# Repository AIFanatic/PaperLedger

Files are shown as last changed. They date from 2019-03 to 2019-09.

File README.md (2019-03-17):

# PaperLedger

Custom made crypto price ticker with alarms

## Getting Started

* [Initial setup](./docs/setup.md "Initial setup")
* [Adding tickers](./docs/add_tickers.md "Adding tickers")
* [Adding alarms](./docs/add_alarms.md "Adding alarms")
* [Updating firmware](./docs/update_firmware.md "Updating firmware")

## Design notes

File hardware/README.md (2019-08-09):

# PaperLedger - Hardware

Note that the currently available materials on the market may be different from the ones listed.

# Bill of materials

## Electronic parts

| Description | SKU | Quantity  | Price  |  Link  |
| --- |:---:| -----:| -----:| -----:|
| TTGO T5 V2.2 ESP32 2.9" EPaper | 32850386996 | 1 | 22.68 USD | [Aliexpress](https://www.aliexpress.com/item/TTGO-T5-V2-2-ESP32-2-9-EPaper-Plus-Module-e-Ink-Speakers/32850386996.html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,searchweb201602_6_10065_10068_10130_10547_319_317_10548_10696_453_10084_454_10083_10618_10307_537_536_10131_10132_10902_10133_10059_10884_10887_321_322_10103,searchweb201603_51,ppcSwitch_0&algo_expid=27d31c4f-6f7f-46df-963b-0b2262c63b45-0&algo_pvid=27d31c4f-6f7f-46df-963b-0b2262c63b45&transAbTest=ae803_4) |
| USB Micro-B Connector Breakout Board | 2586 | 1 | 1.49 USD | [Pololu](https://www.pololu.com/product/2586) |

## 3D Printed parts

| Description | Quantity |
| --- |:---:|
| Front.stl | 1 |
| Back.stl | 1 |
| Buttons.stl | 1 |

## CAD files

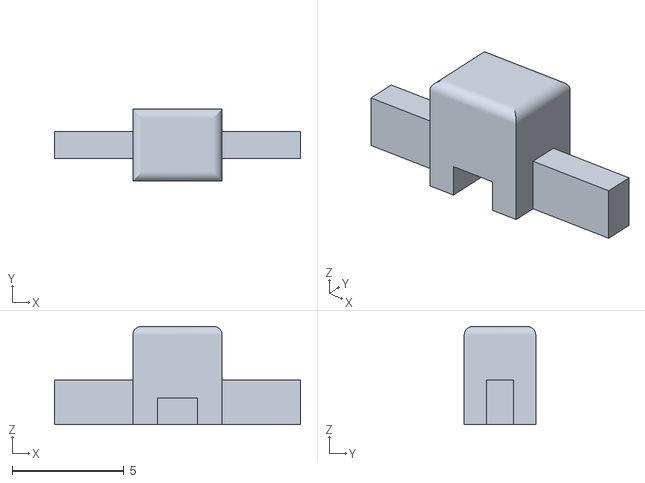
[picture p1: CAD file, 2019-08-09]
hardware/Button_on_off.stl
11.0 x 3.20 x 4.40

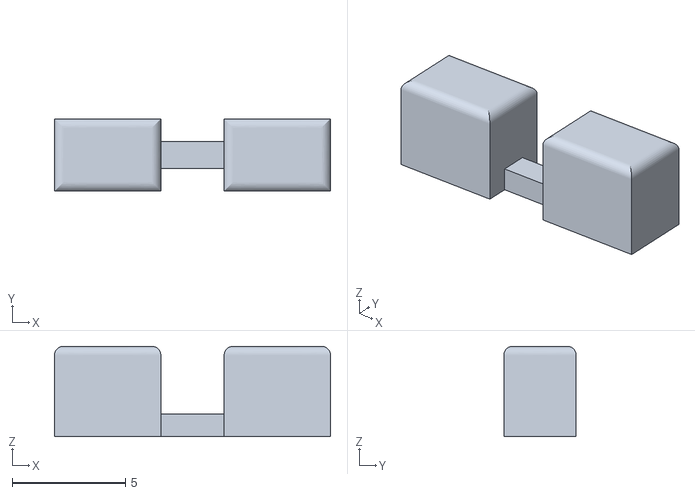
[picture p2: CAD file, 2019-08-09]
hardware/Buttons.stl
12.2 x 3.20 x 4.00

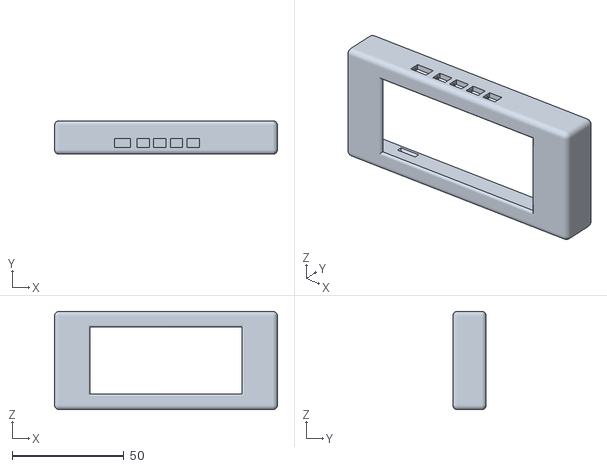
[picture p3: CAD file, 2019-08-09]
hardware/Front.stl
100.0 x 15.0 x 44.0

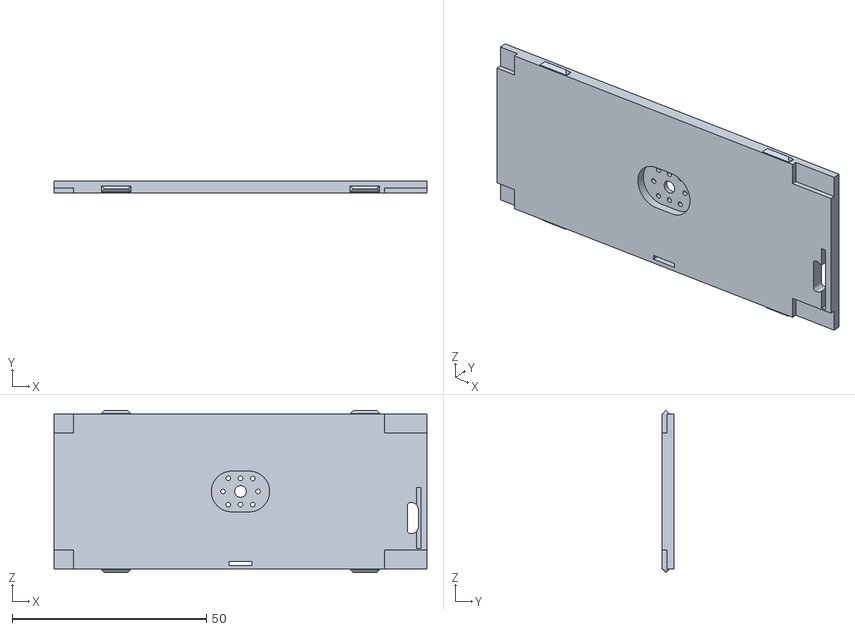
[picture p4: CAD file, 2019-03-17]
hardware/Back.stl
96.0 x 3.01 x 41.8

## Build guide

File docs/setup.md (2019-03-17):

# PaperLedger Guides
## Initial setup

1. Power on the device by connecting the usb cable at the back of the device

2. Wait for the device to boot and show *No Internet*

3. Using another Wifi capable device search for networks and connect to *PaperLedger*

4. Using any browser navigate to *http://paperledger.local*

5. Click *Setup network* and wait for the device to query the available Wifi networks

6. Click on the tick button next to the desired network, enter the Wifi password and click connect.

7. After a few seconds the device should either reboot or go to the main menu, meaning that it is connected

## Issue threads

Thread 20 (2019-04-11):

Solve networking issues

AIFanatic, 2019-04-11:
In GitLab by @nm on Jan 3, 2019, 00:40

Sometimes if in AP mode and the user browses the ip the device crashes

AP first client connect:
```
Guru Meditation Error: Core  1 panic'ed (LoadProhibited). Exception was unhandled.
Core 1 register dump:
PC      : 0x400dbbae  PS      : 0x00060b30  A0      : 0x800dbbd5  A1      : 0x3ffd2930
A2      : 0x3ffd29e8  A3      : 0x3ffb85f4  A4      : 0x3ffcecd8  A5      : 0x3f401867
A6      : 0x00ff0000  A7      : 0xff000000  A8      : 0x00000001  A9      : 0x3ffd2910
A10     : 0x3ffd2938  A11     : 0x3ffcd6f0  A12     : 0x3ffcecd8  A13     : 0x3f401867
A14     : 0x00000072  A15     : 0xff000000  SAR     : 0x00000020  EXCCAUSE: 0x0000001c
EXCVADDR: 0x00000009  LBEG    : 0x4000c46c  LEND    : 0x4000c477  LCOUNT  : 0x00000000

Backtrace: 0x400dbbae:0x3ffd2930 0x400dbbd2:0x3ffd2960 0x400dd539:0x3ffd2980 0x400dd5d1:0x3ffd2a20 0x400dd6f3:0x3ffd2a60 0x400e1c65:0x3ffd2a90 0x400df60d:0x3ffd2ac0 0x400df6ed:0x3ffd2b00 0x400df945:0x3ffd2b50 0x40147ba5:0x3ffd2b70 0x40147e72:0x3ffd2bb0

0x4000c349
0x4000c349: ?? ??:0
0x4000c36b
0x4000c36b: ?? ??:0
0x40116a92:0x3ffbeb80
0x40116a92: handle_dhcp at /Users/ficeto/Desktop/ESP32/ESP32/esp-idf-public/components/lwip/apps/dhcpserver.c:1035
0x4011ea31:0x3ffbeba0
0x4011ea31: udp_input at /Users/ficeto/Desktop/ESP32/ESP32/esp-idf-public/components/lwip/core/udp.c:417
0x401215dd:0x3ffbebe0
0x401215dd: ip4_input at /Users/ficeto/Desktop/ESP32/ESP32/esp-idf-public/components/lwip/core/ipv4/ip4.c:705
0x40127586:0x3ffbec00
0x40127586: ethernet_input at /Users/ficeto/Desktop/ESP32/ESP32/esp-idf-public/components/lwip/netif/ethernet.c:176
0x40115e55:0x3ffbec20
0x40115e55: tcpip_thread at /Users/ficeto/Desktop/ESP32/ESP32/esp-idf-public/components/lwip/api/tcpip.c:474
```

Wifi first connect (coming from AP mode):
```
Guru Meditation Error: Core  1 panic'ed (LoadProhibited). Exception was unhandled.
Core 1 register dump:
PC      : 0x400dbbae  PS      : 0x00060b30  A0      : 0x800dbbd5  A1      : 0x3ffd2930
A2      : 0x3ffd29e8  A3      : 0x3ffb85f4  A4      : 0x3ffcecd8  A5      : 0x3f401867
A6      : 0x00ff0000  A7      : 0xff000000  A8      : 0x00000001  A9      : 0x3ffd2910
A10     : 0x3ffd2938  A11     : 0x3ffcd6f0  A12     : 0x3ffcecd8  A13     : 0x3f401867
A14     : 0x00000072  A15     : 0xff000000  SAR     : 0x00000020  EXCCAUSE: 0x0000001c
EXCVADDR: 0x00000009  LBEG    : 0x4000c46c  LEND    : 0x4000c477  LCOUNT  : 0x00000000

Backtrace: 0x400dbbae:0x3ffd2930 0x400dbbd2:0x3ffd2960 0x400dd539:0x3ffd2980 0x400dd5d1:0x3ffd2a20 0x400dd6f3:0x3ffd2a60 0x400e1c65:0x3ffd2a90 0x400df60d:0x3ffd2ac0 0x400df6ed:0x3ffd2b00 0x400df945:0x3ffd2b50 0x40147ba5:0x3ffd2b70 0x40147e72:0x3ffd2bb0

0x400dbbae
0x400dbbae: fs::FS::open(char const*, char const*) at ??:?
0x4000c46c
0x4000c46c: ?? ??:0
0x4000c477
0x4000c477: ?? ??:0
0x400dbbae:0x3ffd2930
0x400dbbae: fs::FS::open(char const*, char const*) at ??:?
0x400dbbd2:0x3ffd2960
0x400dbbd2: fs::FS::open(String const&, char const*) at ??:?
0x400dd539:0x3ffd2980
0x400dd539: AsyncStaticWebHandler::_fileExists(AsyncWebServerRequest*, String const&) at ??:?
0x400dd5d1:0x3ffd2a20
0x400dd5d1: AsyncStaticWebHandler::_getFile(AsyncWebServerRequest*) at ??:?
0x400dd6f3:0x3ffd2a60
0x400dd6f3: AsyncStaticWebHandler::canHandle(AsyncWebServerRequest*) at ??:?
0x400e1c65:0x3ffd2a90
0x400e1c65: AsyncWebServer::_attachHandler(AsyncWebServerRequest*) at ??:?
0x400df60d:0x3ffd2ac0
0x400df60d: AsyncWebServerRequest::_parseLine() at ??:?
0x400df6ed:0x3ffd2b00
0x400df6ed: AsyncWebServerRequest::_onData(void*, unsigned int) at ??:?
0x400df945:0x3ffd2b50
0x400df945: std::_Function_handler<void (void*, AsyncClient*, void*, unsigned int), AsyncWebServerRequest::AsyncWebServerRequest(AsyncWebServer*, AsyncClient*)::{lambda(void*, AsyncClient*, void*, unsigned int)#7}>::_M_invoke(std::_Any_data const&, void*&&, AsyncClient*&&, std::_Any_data const&, unsigned int&&) at WebRequest.cpp:?
0x40147ba5:0x3ffd2b70
0x40147ba5: AsyncClient::_recv(tcp_pcb*, pbuf*, signed char) at ??:?
0x40147e72:0x3ffd2bb0
0x40147e72: _async_service_task(void*) at AsyncTCP.cpp:?
```

AIFanatic, 2019-04-11:
In GitLab by @nm on Jan 3, 2019, 00:40

Solve Wifi/AP reconnect change credentials crashing

AIFanatic, 2019-04-11:
In GitLab by @nm on Jan 3, 2019, 19:53

changed title from **Solve {-wifi-} issues** to **Solve {+AP+} issues**

AIFanatic, 2019-04-11:
In GitLab by @nm on Jan 3, 2019, 19:53

changed the description

AIFanatic, 2019-04-11:
In GitLab by @nm on Jan 4, 2019, 21:45

changed title from **Solve {-AP-} issues** to **Solve {+networking+} issues**

AIFanatic, 2019-04-11:
In GitLab by @nm on Jan 4, 2019, 21:45

changed the description

AIFanatic, 2019-04-11:
In GitLab by @nm on Jan 25, 2019, 23:40

changed the description

AIFanatic, 2019-04-11:
In GitLab by @nm on Jan 26, 2019, 15:18

Solved AP issues: https://github.com/espressif/arduino-esp32/issues/2283

AIFanatic, 2019-04-11:
In GitLab by @nm on Jan 26, 2019, 17:44

closed

AIFanatic, 2019-07-30:
The device still has issues with connectivity.
It seems that the latest version of Espressif 32 (1.9.0) has some networking issues.
The device behaves unpredictably specially in AP mode (slow, ack lost, cant ping gateway, etc)

By applying the changes below the device seems to be stable so far.
https://github.com/espressif/arduino-esp32/issues/3037#issuecomment-516095167

Closed 2019-04-11.

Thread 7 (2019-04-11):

[Feature Request] Price graph of a coin

BitcoinMitchell, 2019-04-11:
It might be nice to have a graph that shows a coin's price.

How I envision it is being able to select the coin you want to watch (since switching between coins might be a bit too confusing) and just draw a graph by pulling the data from some API.

AIFanatic, 2019-04-11:
It was in my plans to add something like this and after some digging I've found this: https://github.com/G6EJD/ESP32-e-Paper-Weather-Display/blob/master/ESP32_OWM_Current_Forecast_42_epaper_v11.ino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

It seems that a simple graph would be easy enough to implement. Also by combining a candle chart with a volume bar below, there is no need to display the price nor the volume anymore thus simplifying the layout.
Only worry is the size of the screen/chart may become to small to be readable at a comfortable distance.

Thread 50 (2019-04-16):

[Hardware] Add a battery

AIFanatic, 2019-04-16:
A battery would complement the device very well and after some research here is some info.

- In order to not change the case design a maximum battery capacity is around 500mah, this should be enough with deep sleep implemented.
- According to the schematics found at https://github.com/lewisxhe/TTGO-Electronic-Badge/blob/master/schematic/T5_V2.2.pdf the VBAT pin is not connected to the ESP32 so a "manual" connection has to be made, possibly to pin IO34.
- The GPIO on the ESP32 works at a 3.3v level and the battery is 3.7v (4.0v while charging) so a voltage divider has to be added to the board in order to bring the voltages down.
- The board already has a charging circuit but the charging LED (or any charging signal) is not available in the GPIO header, so either "charging mode" is detected by voltage increase on VBAT or "LED_G LED0603 BLUE" has to be remapped to the available GPIO.

AIFanatic, 2019-05-13:
Updates:
- In addition to the VBAT pin the charging pin (VBUS/CHRG) is hardwired to the onboard USB which will be hard to get around without some hackish solutions. Ideally a vertical USB connector would replace the existing one thus removing the need for an extra USB.
- The cases are likely to be reprinted since the battery barely fits the existing model. A 2mm increase in depth should be enough to accommodate the battery nicely.
- The device consumes ~85mA while powered, peaking to ~150mA when pulling data.
- In deep sleep mode the device consumes 7mA which is higher than the researched values of around 10μA (https://lastminuteengineers.com/esp32-sleep-modes-power-consumption/). This is likely to be related with the onboard LED's (charding and power) that are always powered on. Ideally these would be removed in order to save power.
- Software wise, deep sleep can be implemented with ease and a prototype has been sketched out. The network connection and deep sleep functionality have to ported out of "Manager" into the modules that require it (eg: TickerView). The "Manager" module has to store the current view in RTC in order to be aware of what view the module is at since the CPU and RAM are powered off in deep sleep.

Hackish solution:
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

AIFanatic, 2019-07-28:
Updates:
- A new board has been manufactured which includes the following changes:
   - Remove SM_20PIN header.
   - Replace SM_20PIN pads with PCB through-hole.
   - Remove MICRO_USB_SMT.
   - Replace MICRO_USB_SMT pads with PCB though-hole.
   - Remove LED_G LED0603 BLUE (charging LED)
   - Remove LED_G2 LED_G LED0603 GREEN (power LED)
   - Connect VBAT with pin 13 on SM_20PIN (IO34).
   - Connect CHRG on TP4054 with pin 14 on SM_20PIN (IO33)
   - Connect RED LED to pin 12 SM_20PIN (IO26)

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

[new_board_schematic.pdf](https://github.com/AIFanatic/PaperLedger/files/3438825/new_board_schematic.pdf)

Closed 2019-08-10.

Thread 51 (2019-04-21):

[Connectivity] Device goes to Welcome screen after a while and gets stuck

AIFanatic, 2019-04-21:
Issue reported from DaveF:
https://bitcointalk.org/index.php?topic=5113453.msg50687270#msg50687270
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

Member StackGambler confirmed the issue:
>@StackGambler
> Same here. Pretty minor issue, but annoying when it happens.

BitcoinMitchell, 2019-04-25:
I haven't had this happen to me yet. Will keep an eye on it though.

AIFanatic, 2019-05-15:
It seems that by flashing the development branch firmware the issue disappeared, closing.

Closed 2019-05-15.

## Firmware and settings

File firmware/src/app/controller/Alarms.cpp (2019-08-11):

#include "Alarms.h"

#include "../Manager.h"

Alarms::Alarms(Manager *_manager) {
    manager = _manager;

    bool tickersFileExists = manager->filesystem->exists(SPIFFS, FILE_TICKERS);

    if(!tickersFileExists) {
        Serial.print("Tickers.json is not valid, creating...");

        manager->filesystem->writeFile(SPIFFS, FILE_TICKERS, "[]");
    }
};

Alarms::~Alarms() {
};

bool Alarms::add(const char *id, const char *currency, const char *price, int duration, int type, int frequency, int beeps) {

    int coinIndex = manager->tickers->getIndexOf(id, currency);

    if(coinIndex == -1) {
        return false;
    }

    String tickers = manager->tickers->get();
    DynamicJsonBuffer jsonBuffer;
    JsonArray& tickersArray = jsonBuffer.parse(tickers);

    DynamicJsonBuffer alarmBuffer;
    JsonObject& alarm = alarmBuffer.createObject();
    alarm["price"] = price;
    alarm["duration"] = duration;
    alarm["type"] = type;
    alarm["frequency"] = frequency;
    alarm["beeps"] = beeps;

    tickersArray[coinIndex]["alarms"].as<JsonArray>().add(alarm);
    
    String str;
    tickersArray.printTo(str);
    return manager->filesystem->writeFile(SPIFFS, FILE_TICKERS, str.c_str());
}

bool Alarms::remove(const char *id, const char *currency, int index) {
    int coinIndex = manager->tickers->getIndexOf(id, currency);

    if(coinIndex == -1) {
        return false;
    }

    String tickers = manager->tickers->get();
    DynamicJsonBuffer jsonBuffer;
    JsonArray& tickersArray = jsonBuffer.parse(tickers);

    tickersArray[coinIndex]["alarms"].as<JsonArray>().remove(index);

    String str;
    tickersArray.printTo(str);

    return manager->filesystem->writeFile(SPIFFS, FILE_TICKERS, str.c_str());
}

void Alarms::checkAlarms() {
    String str = manager->tickers->get();

    DynamicJsonBuffer buffer;
    JsonArray& tickersArray = buffer.parse(str);

    bool alarmTriggered = false;

    for(int i = 0; i < tickersArray.size(); i++) {
        double tickerPrice = tickersArray[i]["price"];

        JsonArray& alarms = tickersArray[i]["alarms"].as<JsonArray>();

        for(int j = 0; j < alarms.size(); j++) {
            JsonObject& alarm = alarms[j].as<JsonObject>();

            double price = alarm["price"];
            int duration = alarm["duration"];
            int type = alarm["type"];
            int frequency = alarm["frequency"];
            int beeps = alarm["beeps"];

            if(tickerPrice > 0) {
                if((type == TYPE_ABOVE && tickerPrice >= price) ||
                   (type == TYPE_BELOW && tickerPrice <= price)) {
                    manager->speaker->beep(frequency, duration / beeps, beeps);
                    manager->speaker->mute();
                    
                    alarms.remove(j);
                    alarmTriggered = true;
                }
            }
        }
    }

    if(alarmTriggered) {
        String str;
        tickersArray.printTo(str);

        manager->filesystem->writeFile(SPIFFS, FILE_TICKERS, str.c_str());
    }
}

void Alarms::requestAddAlarms(AsyncWebServerRequest *request) {
    if(!request->hasParam("id", true) || !request->hasParam("currency", true) || 
       !request->hasParam("price", true) || !request->hasParam("duration", true) ||
       !request->hasParam("type", true) || !request->hasParam("frequency", true) ||
       !request->hasParam("beeps", true)) {
        manager->webserver->requestInvalid(request);
        return;
    }

    const char *id = request->getParam("id", true)->value().c_str();
    const char *currency = request->getParam("currency", true)->value().c_str();
    const char *price = request->getParam("price", true)->value().c_str();
    int duration = request->getParam("duration", true)->value().toInt();
    int type = request->getParam("type", true)->value().toInt();
    int frequency = request->getParam("frequency", true)->value().toInt();
    int beeps = request->getParam("beeps", true)->value().toInt();


    bool ret = add(
        id, currency, 
        price, duration, 
        type, frequency, 
        beeps
    );

    request->send(200, "application/json", "{\"status\":\"ok\",\"message\":" + String(ret) + "}");
};

void Alarms::requestRemoveAlarms(AsyncWebServerRequest *request) {
    if(!request->hasParam("id", true) || !request->hasParam("currency", true) || !request->hasParam("index", true)) {
        manager->webserver->requestInvalid(request);
        return;
    }

    const char *id = request->getParam("id", true)->value().c_str();
    const char *currency = request->getParam("currency", true)->value().c_str();
    int index = request->getParam("index", true)->value().toInt();

    bool ret = remove(id, currency, index);

    request->send(200, "application/json", "{\"status\":\"ok\",\"message\":" + String(ret) + "}");
};

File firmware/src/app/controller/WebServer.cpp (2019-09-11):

#include "WebServer.h"

#include "../Manager.h"

WebServer::WebServer(Manager *_manager) {
    manager = _manager;

    DefaultHeaders::Instance().addHeader("Access-Control-Allow-Origin", "*");
};

WebServer::~WebServer() {
};

void WebServer::requestNotFound(AsyncWebServerRequest *request) {
    request->send(200, "application/json", "{\"status\":\"error\",\"message\":\"Endpoint not found\"}");
};

void WebServer::requestInvalid(AsyncWebServerRequest *request) {
    request->send(200, "application/json", "{\"status\":\"error\",\"message\":\"Invalid request\"}");
};

void WebServer::requestWifiStatus(AsyncWebServerRequest *request) {
    DynamicJsonBuffer jsonBuffer;
    JsonObject& response = jsonBuffer.createObject();
    JsonObject& message = response.createNestedObject("message");

    response["status"] = "ok";

    message["ssid"] = WiFi.SSID();
    message["rssi"] = WiFi.RSSI();
    message["internet"] = hasInternetAccess;
    
    String jsonStr;
    response.printTo(jsonStr);
    request->send(200, "application/json", jsonStr);
};

void WebServer::requestWifiList(AsyncWebServerRequest *request) {
    DynamicJsonBuffer jsonBuffer;
    JsonObject& response = jsonBuffer.createObject();

    response["status"] = "ok";

    JsonArray& message = response.createNestedArray("message");

    int n = WiFi.scanNetworks();

    if (n != 0) {
        for (int i = 0; i < n; ++i) {
            JsonObject& newWifi = message.createNestedObject();
            
            newWifi["ssid"] = WiFi.SSID(i);
            newWifi["rssi"] = WiFi.RSSI(i);
            newWifi["algo"] = WiFi.encryptionType(i);
            newWifi.set<int>("algo", WiFi.encryptionType(i));

            delay(10);
        }
    }
    
    String jsonStr;
    response.printTo(jsonStr);
    request->send(200, "application/json", jsonStr);
};

void WebServer::requestWifiConnect(AsyncWebServerRequest *request) {
    if(!request->hasParam("ssid", true) || !request->hasParam("password", true)) {
        requestInvalid(request);
        return;
    }

    const char *ssid = request->getParam("ssid", true)->value().c_str();
    const char *password = request->getParam("password", true)->value().c_str();

    manager->settings->set("ssid", ssid);
    manager->settings->set("password", password);

    request->send(200, "application/json", "{\"status\":\"ok\",\"message\":\"connecting\"}");

    needNetworkReconnect = true;
};

void WebServer::requestWifiDisconnect(AsyncWebServerRequest *request) {
    request->send(200, "application/json", "{\"status\":\"ok\",\"message\":\"disconnecting\"}");
    disconnectWifi();
};

void WebServer::reset() {
    dnsServer.stop();
    server.reset();
}

void WebServer::begin() {
    if (MDNS.begin(AP_NAME))
    {
        Serial.println("MDNS responder started");
    }

    server.serveStatic("/", SPIFFS, "/web").setDefaultFile("index.html");

    server.on("/display/draw", HTTP_POST, [this](AsyncWebServerRequest *request) {
        if(request->params() == 0) {
            requestInvalid(request);
            return;
        }

        String name = request->getParam(0)->name();
        String params = request->getParam(0)->value();

        if(name.equals("body")) {
            manager->render->drawFromJson(params);
            request->send(200, "application/json", "{\"status\":\"ok\",\"message\":\"drawing\"}");
        }
    });

    server.on("/data/wifi/list", HTTP_GET, [this](AsyncWebServerRequest *request) {
        requestWifiList(request);
    });

    server.on("/data/wifi/status", HTTP_GET, [this](AsyncWebServerRequest *request) {
        requestWifiStatus(request);
    });

    server.on("/data/wifi/connect", HTTP_POST, [this](AsyncWebServerRequest *request) {
        requestWifiConnect(request);
    });

    server.on("/data/wifi/disconnect", HTTP_POST, [this](AsyncWebServerRequest *request) {
        requestWifiDisconnect(request);
    });

    server.on("/data/tickers/list", HTTP_GET, [this](AsyncWebServerRequest *request) {
        manager->tickers->requestTickers(request);
    });

    server.on("/data/tickers/add", HTTP_POST, [this](AsyncWebServerRequest *request) {
        manager->tickers->requestAddTickers(request);
    });
    
    server.on("/data/tickers/order", HTTP_POST, [this](AsyncWebServerRequest *request) {
        manager->tickers->requestOrderTickers(request);
    });

    server.on("/data/tickers/remove", HTTP_POST, [this](AsyncWebServerRequest *request) {
        manager->tickers->requestRemoveTickers(request);
    });

    server.on("/data/alarms/add", HTTP_POST, [this](AsyncWebServerRequest *request) {
        manager->alarms->requestAddAlarms(request);
    });

    server.on("/data/alarms/remove", HTTP_POST, [this](AsyncWebServerRequest *request) {
        manager->alarms->requestRemoveAlarms(request);
    });

    server.on("/data/settings/list", HTTP_GET, [this](AsyncWebServerRequest *request) {
        manager->settings->requestSettings(request);
    });

    server.on("/data/settings/change", HTTP_POST, [this](AsyncWebServerRequest *request) {
        manager->settings->requestChangeSettings(request);
    });

    server.on("/data/battery/status", HTTP_GET, [this](AsyncWebServerRequest *request) {
        manager->battery->requestBatteryStatus(request);
    });

    server.on("/update", HTTP_POST, [this](AsyncWebServerRequest *request){
        manager->updater->requestUpdate(request);
    },[this](AsyncWebServerRequest *request, String filename, size_t index, uint8_t *data, size_t len, bool final){
        manager->updater->requestUpdateUpload(request, filename, index, data, len, final);
    });

    server.onNotFound([this](AsyncWebServerRequest *request) {
        if(getWifiMode() == WIFI_MODE_AP) {
            String apName = String(AP_NAME);
            apName.toLowerCase();
            String url = "http://" + apName + ".local";
            request->redirect(url);
            return;
        }
        requestNotFound(request);
    });

    MDNS.addService("http", "tcp", 80);

    server.begin();
}

String WebServer::get(String url) {
    http.begin(url);
    int httpCode = http.GET();
 
    if (httpCode == 0) {
        Serial.println("Error on HTTP request");
        return "";
    }
 
    String payload = http.getString();
    
    http.end(); //Free the resources

    return payload;
};

String WebServer::post(String url, String params) {
    http.begin(url);
    int httpCode = http.POST(params);
 
    if (httpCode == 0) {
        Serial.println("Error on HTTP request");
        return "";
    }
 
    String payload = http.getString();
    
    http.end(); //Free the resources

    return payload;
}

bool WebServer::disconnectWifi() {
    return WiFi.disconnect();
}

bool WebServer::reconnectWifi() {
    return WiFi.reconnect();
}
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

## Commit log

2019-01-09 Added ticker scroll using buttons
2019-01-14 Fixed layout add ticker list width. Added vol_24h default to tickers.
    [Render.cpp, Tickers.cpp]
2019-01-23 Revert "Ported alarms to separate class"
    This reverts commit f87e2ab9c21d7c55b37d223041cb9d95919ed366.
    [Alarms.cpp, Tickers.cpp]
2019-01-25 Fixed bug with tickers/alarms/settings. JsonArray passing pointer gets lost
    [Alarms.cpp, Settings.cpp, Tickers.cpp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]
2019-01-26 Better handling of ArduinoJson
2019-01-27 Changed speaker to beep on alarm. Showing more meaningful errors on update failed
    [Alarms.cpp, Speaker.cpp, WebServer.cpp]
2019-03-17 Changed project structure
    [Back.stl, Buttons.stl, Front.stl]
2019-04-10 Added option to mute speaker (on menu switches)
2019-07-28 Added battery view and controller https://github.com/AIFanatic/PaperLedger/issues/50
    [Battery.cpp, WebServer.cpp, variables.h]
2019-07-28 Changed Front case to accomodate battery. Gave more room to usb holder pcb. Closed old usb connector hole. Better fitting of on/off switch https://github.com/AIFanatic/PaperLedger/issues/50
    [Buttons.stl, Front.stl]
2019-07-30 Added ON/OFF button
    [Button_on_off.stl]
2019-07-31 Added BatteryView and RTC in order to suit battery https://github.com/AIFanatic/PaperLedger/issues/50
    [Battery.cpp]
2019-08-10 Fixed DeepSleep state issues. Fixed GxEPD2 clearScreen issues. Fixed StatusView issues.
    [Render.cpp]
2019-08-10 Minimized noise created by Speaker on boot/shutdown
    [Battery.cpp, Render.cpp, Speaker.cpp]
2019-08-11 Refactored Speaker controller Fixed networking icons
    [Alarms.cpp, Render.cpp, Speaker.cpp]
2019-09-11 Improved deep sleep cycle and fixed bug when no networks are available
    [Speaker.cpp, WebServer.cpp, variables.h]
